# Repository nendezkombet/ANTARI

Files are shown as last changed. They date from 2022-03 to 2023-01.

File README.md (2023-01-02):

## Table of contents

- [Overview](#overview)
- [Features](#features)
- [Default Layout](#default-layout)
- [Lightroom Layout](#lightroom-layout)
- [PCB](#pcb)
- [BOM](#bom)
- [Case](#case)
- [Assembly Guide](#assembly-guide)
- [Firmware](#firmware)

## Overview

ANTARI is 4x4 macropad supports analog potentiometer, rotary encoders, Oled screen, passive buzzer, 3.5mm TRS socket for sending out serial data like midi output and more. The rotary encoder also outputs midi signal when the keyboard is switched to 'Lightroom' dedicated layer, once you pressed an letter key the knob will output a midi cc signal with different parameter, which allows you use a knob to adjust up to 45 sliders in lightroom with Lightroom keymap, most importantly, the value will not jump or jitter, oppositely it moves relatively and smoothly. The oled screen will show you the last letter key you pressed and every information you need. For detailed demo you can visit my youtube [video](https://www.youtube.com/watch?v=S6qfb3bq990&t=147s&ab_channel=Synthvestigator).

Designer and maintainer: [sandipratama/nendezkombet](https://github.com/nendezkombet) 









For hardware midi controller the PCB has 3.5mm TRS female socket footprint ( 3.5mm TRS male jack to 5-pin midi midi cable as connector required ), for this specific purpose the programaing code can be done with arduinoIDE.

## Features

- Cheap to build.
- Easy to source components.
- Easy to build.
- MX style switch and Kailh low profile V2 switch compatible
- Arduino Pro Micro powered.
- QMK compatible.
- RGB backlighting support (optional).
- Rotary encoder support.
- Passive buzzer support.
- Two placement oled LCD support.
- Hardware midi controller support.
- Can be battery powered ( as portable controller like midi or lighting controller ).
- Completely open-source.

## Default Layout

Default layout just for ordinary macropad with rotary encoder, passive buzzer for layer indicator, RGB underglow and analog potentiometer if enabled.

keyboard-layout (2)

Because every people have their specific keymap setting, i decided setting up the default keymap with alphabet key so you can edit every function key as you want and compile your own firmware later. If you decided with rotary encoder it's function as system volume and instantly enabled by default. 

## Lightroom Layout 

Every key in the lightroom keymap has 3 different midi cc's number, you can access every cc's with tapping the key 1-3 times. Activated cc's will displayed in the oled LCD display. You you can visit my youtube [video](https://www.youtube.com/watch?v=S6qfb3bq990&t=147s&ab_channel=Synthvestigator) for future detail.

For this specific lightroom keymap doesn't works with vial it is mean fixed keymap, just flash with flashing file provided.

The pictures below showed first layer on the left and second layer on the right.

keyboard-layout1 (2)   keyboard-layout t(2)

## PCB

PCB legend showed components placement and detail footprints information.

PCB

## BOM

|Parts|Footprint|Quantity|
|:---|:---|:---|
|WS2812B RGB LED |5050|8|
|100nF capacitor|0805|8|
|MX switch or Kailh low V2 switch |3 or 5 pin|16|
|1N4148 diode |SOD-123 or axial|16|
|Rotary encoder|EC11|1|
|Arduino Promicro |32u4|1|
|220ohm resistor|0805 or axial|3|
|Reset button switch |6mm*2.5mm|1|
|Passive buzzer |12mm|1|
|Oled LCD display |SSD1306|1|
|B10K Analog potentiometer (optional) | RV09 or RK09|1|
|3.5mm TRS female socket (optional) |PJ313|1|
|Micro slide switch (optional)|MSS22D18 |1|
|9V battery (optional) ||1|
|8mm M2 "MALE TO FEMALE" brass standoff|round knurled|4|
|8mm M2 "FEMALE TO FEMALE" brass standoff|round knurled|4|
|5-6mm M2 screw|-|8|
|3.5mm TRS jack to 5-pin midi din male socket (optional) |see detail below|1|

51kXivjBTuL _AC_SX425_

you can build by your self, wiring instruction can by found in the google search engine.

## Case

Stacked acrylic case cutting file can be open with Adobe Illustrator or Corel Draw and ready for cutting process.

## Assembly Guide

See inside cutting file folder !!!

## Firmware

The firmware is fully QMK, see [build environment setup](https://docs.qmk.fm/#/getting_started_build_tools) then the [make instructions](https://docs.qmk.fm/#/getting_started_make_guide) for more information. 

## Firmware flashing :

Open QMK Toolbox and locate The .hex file you compiled before or use ready flash default keymap

## Enter the bootloader :

Press the button twice on the back of the PCB than hit flash

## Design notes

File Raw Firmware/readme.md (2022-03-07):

# Antari

Antari
PCBlegend

ANTARI is 4x4 macropad supports analog potentiometer, rotary encoders, Oled screen, passive buzzer, 3.5mm TRS socket for sending out serial data like midi output and more. The rotary encoder also outputs midi signal when the keyboard is switched to 'Lightroom' dedicated layer, once you pressed an letter key the knob will output a midi cc signal with different parameter, which allows you use a knob to adjust up to 45 sliders in lightroom with Lightroom keymap, most importantly, the value will not jump or jitter, oppositely it moves relatively and smoothly. The oled screen will show you the last letter key you pressed and every information you need. 

* Keyboard Maintainer: [sandipratama](https://github.com/nendezkombet)
* Hardware Supported: *The PCBs, controllers supported*
* Hardware Availability: https://github.com/nendezkombet/antari

Make example for this keyboard (after setting up your build environment):

    make antari:default

Flashing example for this keyboard:

    make antari:default:flash

See the [build environment setup](https://docs.qmk.fm/#/getting_started_build_tools) and the [make instructions](https://docs.qmk.fm/#/getting_started_make_guide) for more information. Brand new to QMK? Start with our [Complete Newbs Guide](https://docs.qmk.fm/#/newbs).

## Bootloader

Enter the bootloader in 3 ways:

* **Bootmagic reset**: Hold down the key at (0,0) in the matrix (usually the top left key or Escape) and plug in the keyboard
* **Physical reset button**: Briefly press the button on the back of the PCB - some may have pads you must short instead
* **Keycode in layout**: Press the key mapped to `RESET` if it is available

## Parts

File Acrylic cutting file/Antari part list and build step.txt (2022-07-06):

Macropad purpose :

1. 8x WS2812B RGB LEDs ( optional )
2. 8x SMD 0603 100nF capacitors or bigger capacitor 0805 will do but little bit tricky for soldering ( this part just for prevent noise/flicker )
3. 12-16x Cherry MX style switch or kailh low provile V2 switch 
4. 1x EC11 rotary encoder ( optional )
5. 4x 8mm M2 "MALE TO FEMALE" brass standoff
6. 4x 8mm M2 "FEMALE TO FEMALE" brass standoff
7. 8x 5-6mm height M2 screw
8. 1x Arduino Promicro 32u4 5v
9. 1x 220ohm or 330ohm resistor for RGB data line
10. 1x micro switch for reset button
11. 1x 128x32 oled LCD module ( optional )
12. 16x diode 1n4148m or SMD diode 1n4148w SOD123 will do ( labeled T4 )
13. 1x Passive buzzer 12mm ( optional )

ANTARI USED PIN LIST :

COL pin list (5, 8, 7, 6 )
ROW pin list (15, 10, 16, 14 )

1. Buzzer (9) 
2. RGB LEDs (A3) 
3. i2c (2, 3 ) 
4. Analog potentiometer (4)
5. Encoder (A0, A1)

ANTARI BUILD STEP :

Note : 
// Using solder flux very recomended !!!
// Prepare solder sucker if you make mistake
// Clip the leg of the component if it's to long
// Don't skip the build step

1. Solder 8 RGB led L1-L8 
2. Solder Capacitor C1-C8 
3. Solder resistor 220ohm/330ohm on R1 solder hole/pad ( for rgb leds data line )
4. Solder the encoder,reset switch,buzzer and oled lcd
5. Solder arduino pin header ( just pin header, for arduino do it in the last step )
6. Attach all top plates with 10mm M2 "MALE TO FEMALE" brass standoff
7. Lock with 10mm M2 "FEMALE TO FEMALE" brass standoff in every corner
8. Attach the switch buttons and tiddy up
9. Solder the switch 
10.Solder arduino to pin header
11.Attach and screw all bottom plate on to PCB 
13.Ready for firmware flashing

Other component like power slide switch , battery socket, trs female socket and battery just free to solder without follow the build step.
For midi connector cable wiring you can search on internet and make sure your wiring match with midi out on the PCB ex. TX-TX, VCC-VCC, and GND-GND

if you have any question and find some bugs please contact me @synthvestigator.gmail or comment in my youtube video for this project @synthvestigator

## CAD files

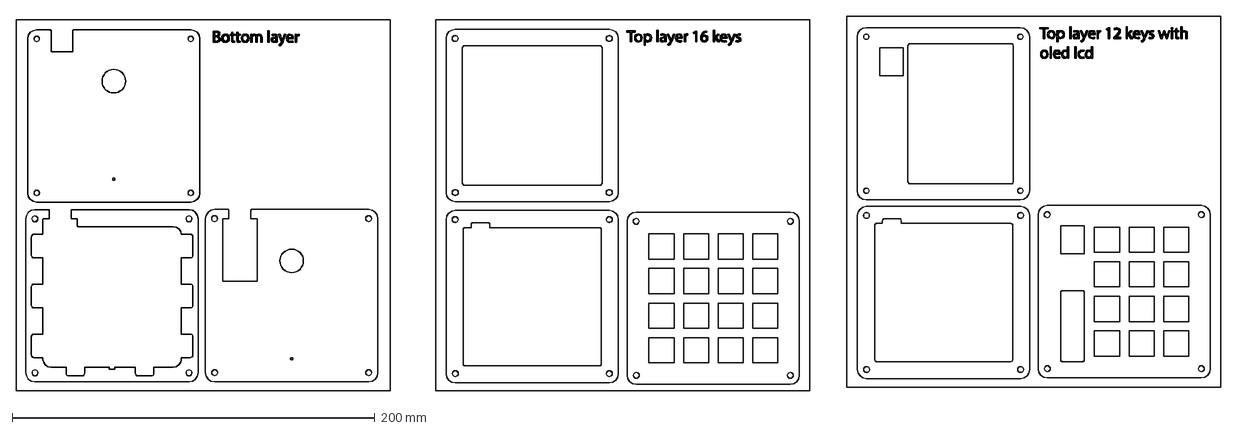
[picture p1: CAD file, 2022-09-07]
Acrylic cutting file/Antari DXF cutting file.dxf
664.4 x 206.7 mm

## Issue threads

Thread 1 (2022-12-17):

ERROR 1 COMPILING

fyrus7, 2022-12-17:
Compile error 1

☒ antari: NO_ACTION_MACRO in config.h is no longer a valid option and should be removed
☒ antari: NO_ACTION_FUNCTION in config.h is no longer a valid option and should be removed
⚠ antari: PRODUCT_ID in config.h is deprecated in favor of `usb.pid` in info.json and will be removed at a later date
⚠ antari: VENDOR_ID in config.h is deprecated in favor of `usb.vid` in info.json and will be removed at a later date
⚠ antari: PRODUCT in config.h is deprecated in favor of `keyboard_name` in info.json and will be removed at a later date
⚠ antari: MANUFACTURER in config.h is deprecated in favor of `manufacturer` in info.json and will be removed at a later date
⚠ antari: DEVICE_VER in config.h is deprecated in favor of `usb.device_version` in info.json and will be removed at a later date

fyrus7, 2022-12-18:
update to new QMK requirement.

fyrus7, 2022-12-18:
update to new QMK requirement seems to correct the error.

Closed 2022-12-18.
